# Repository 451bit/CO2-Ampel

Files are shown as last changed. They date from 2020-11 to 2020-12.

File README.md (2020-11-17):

# CO2-Ampel
ESP32 basierte CO2-Ampel für Schulen
## Inhalt
* Bau
* Programmierung
* Blynk-Server einrichten
* HTTP-Server einrichten
* Case
## Bau
* Die Pinleisten von beiden Seiten unten an den ESP anlöten. VORSICHT bei den Pins am Anschlusskabel des Displays. Der Lötkolben darf das Kabel auf keinen Fall berühren. Darauf achten, dass die Pinleisten möglichst vertikal stehen.

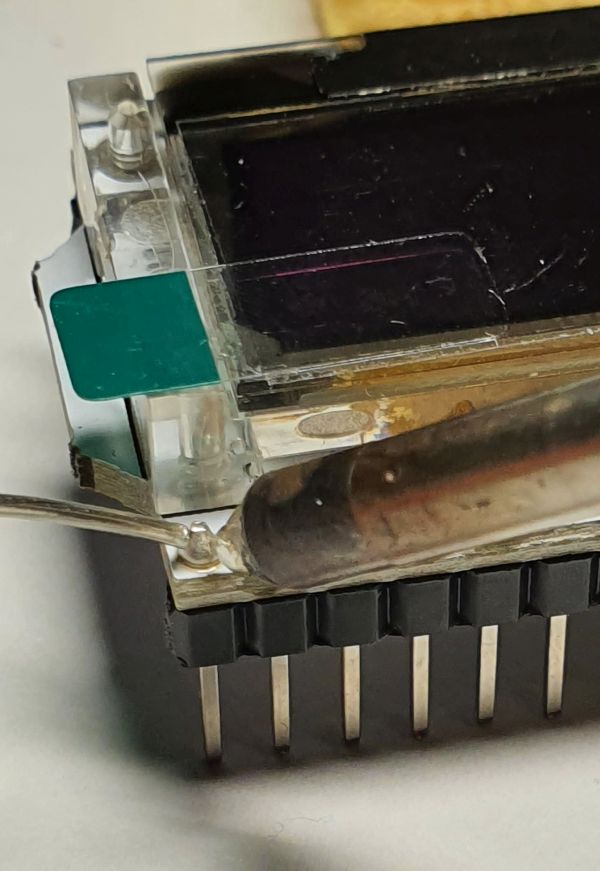
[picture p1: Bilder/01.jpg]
Bild 1

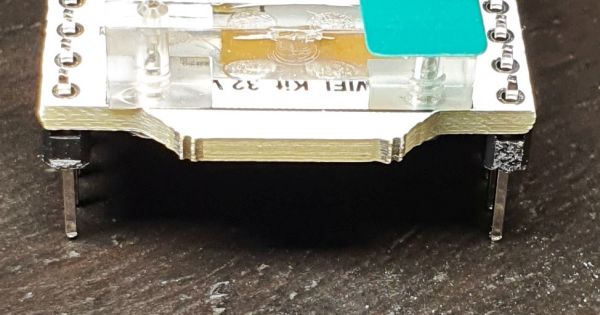
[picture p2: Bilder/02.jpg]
Bild 2


* Mit einem Multimeter an allen benachbarten Pins sicherstellen, dass keine Verbindung zwischen den Pins besteht (Widerstand sehr hoch)
* Die Pinleiste vom DHT22 mit einer Zange abknipsen und die Pin-Rest aus den Löchern entfernen (Lötzinn natürlich vorher erwärmen).

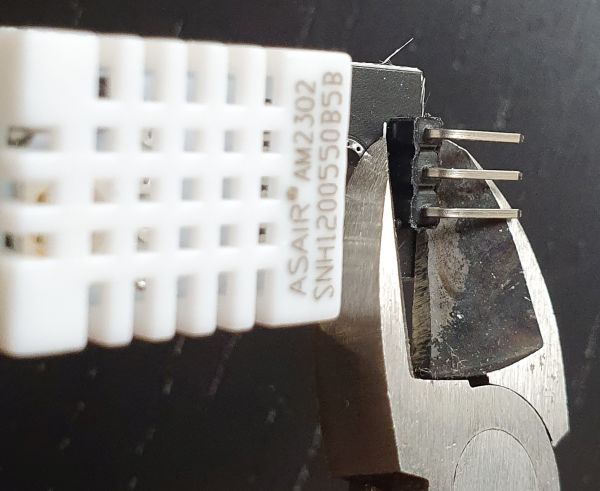
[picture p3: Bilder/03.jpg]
Bild 3

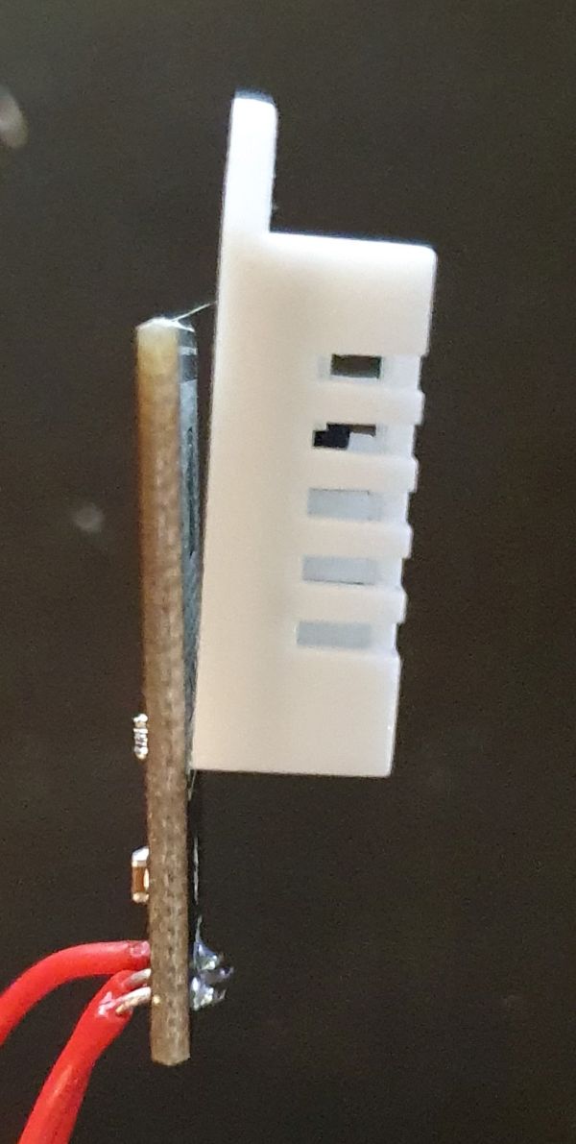
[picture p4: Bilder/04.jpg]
Bild 4


* Den Stecker-Anschluss vom Z19B mit einer Zange abknipsen.

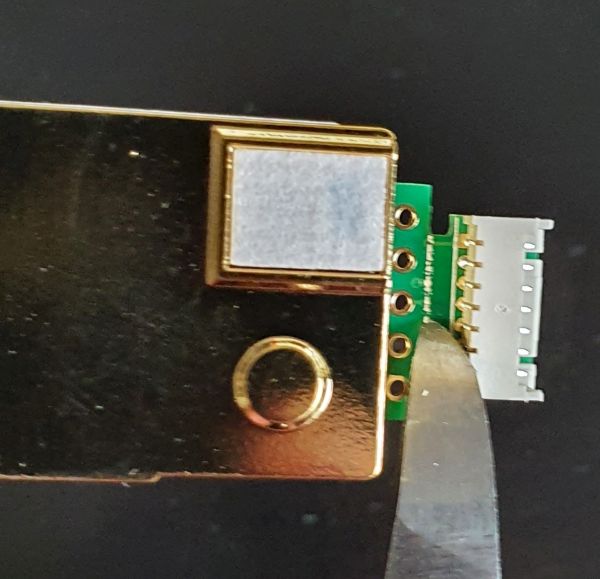
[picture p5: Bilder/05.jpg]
Bild 5

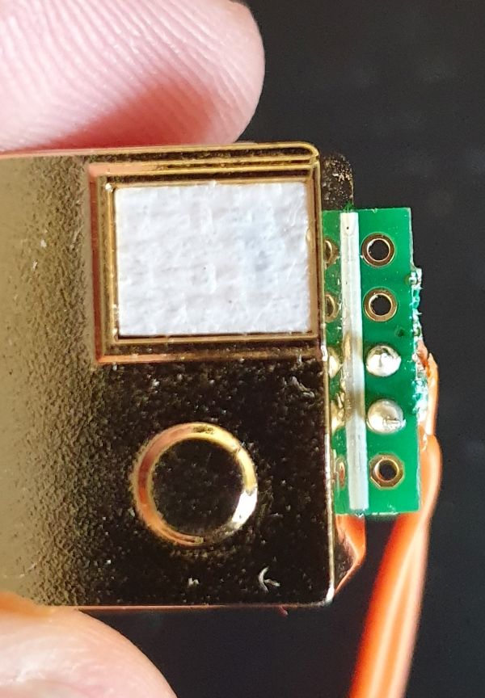
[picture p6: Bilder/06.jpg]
Bild 6


* Abstandsbolzen wie auf dem Bild an die Platine schrauben <br>

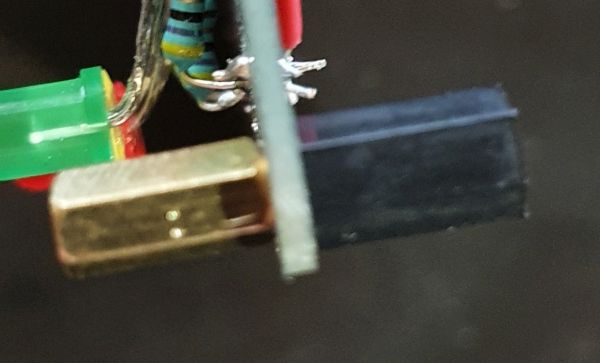
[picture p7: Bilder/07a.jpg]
Bild 7


WICHTIGE HINWEISE: Die Verkabelung exakt wie im Schaltplan einhalten (nicht wie teilweise auf den Bildern), ansonsten passt das Case evtl. nicht. 

* Den ESP, die Widerstände und die LEDs nach dem Schaltbild auf der Platine verlöten.
	* LED-Beine möglichst lang lassen, damit die LEDs variabel im Case plaziert werden können und darauf achten, dass die Kathode (kurzes Beinchen, abgeflachte Seite) wie im Schaltbild rechts ist/mit Widerstand und Gnd/- verbunden ist.
 
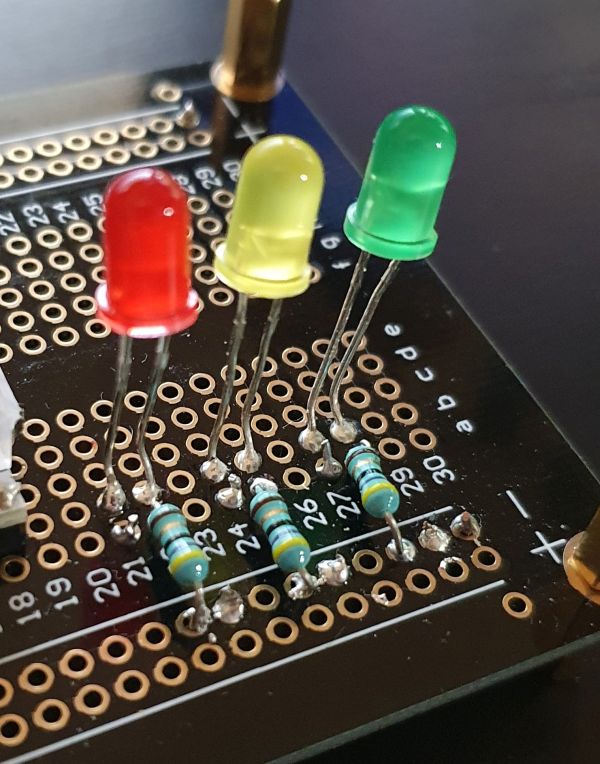
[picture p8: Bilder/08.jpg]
Bild 8

 
* Den ESP komplett in die Platine einlassen und von der Unterseite verlöten (ansonsten sitzt er zu hoch für das Case, evtl mit Tesa festkleben)
 
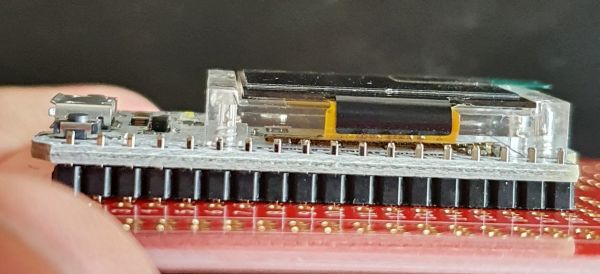
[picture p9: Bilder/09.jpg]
Bild 9

 
* Alle Kabelverbindungen auf der Unterseite der Platine verlöten (auf dem Bild sind 5V- und GND- Leiste anders als im Schaltplan verlötet, bitte an den Schaltplan halten).

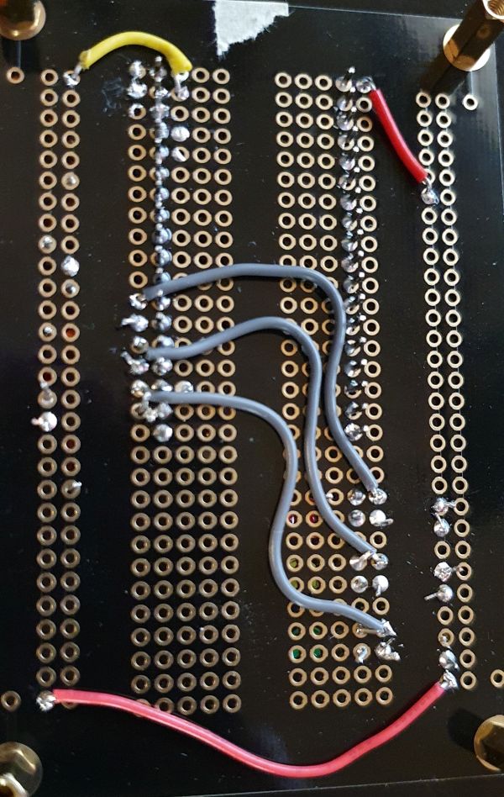
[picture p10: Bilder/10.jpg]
Bild 10


* Für den DHT22 drei und den Z19B vier relativ lange Kabel (ca. 10 cm) wählen (sie werden nicht direkt auf der Platine verlötet) und nach dem Schaltplan an die Unterseite der Sensoren und auf die Platine löten.

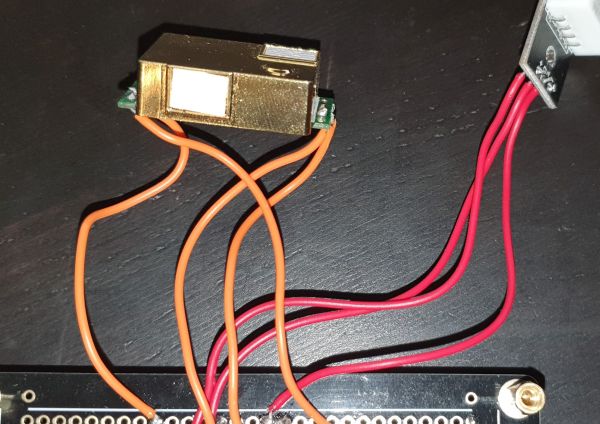
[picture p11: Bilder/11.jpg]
Bild 11


## Programmierung (bezieht sich auf Arduino-IDE auf Windows, auf MacOS sind die Einstellungen teilweise an anderen Stellen)
* Arduino-IDE herunterladen (https://www.arduino.cc/)
* Repos in der IDE einbinden:
	* Datei -> Voreinstellungen
	* Bei "Zusätzliche Boardverwalter-URLs" folgendes Einfügen: https://resource.heltec.cn/download/package_heltec_esp32_index.json
	* IDE neustarten
* Board auswählen
	* Werkzeuge -> Board -> Boardverwalter
	* Suche nach "Heltec ESP32"
	* "Heltec ESP32 Series Dev-boards" installieren und Boardverwalter schließen
	* Werkzeuge -> Board -> Heltec ESP32 Arduino -> WiFi Kit 32
* Bibliotheken einbinden
	* Werkzeuge -> Bibliotheken verwalten
	* Folgende Bibliotheken installieren:
		* Blynk
		* DHT sensor library
		* ESP32 AnalogWrite
		* Heltec ESP32 Dev-Boards
		* SimpleTimer
* Den ESP per USB-Kabel mit dem PC verbinden und unter Werkzeuge -> Port den korrekten COM-Port für den ESP wählen (meist nicht COM1) 
* Arduino-Code herunterladen und die Datei CO2-Ampel.ino in der Arduino-IDE öffnen.
* In der Configuration.h müssen die Zugangsdaten für WiFi bzw Blynk und den Webserver eingetragen werden (nur, falls die Daten online gestellt werden sollen):
* Sketch auf den ESP übertragen
## Blynk einrichten
* Blynk-App herunterladen
* Login oder Account erstellen
* Neues Projekt erstellen
	* Projektname wählen
	* Als Device ESP32 Dev Board wählen
	* Create
* Oben auf die Mutter klicken und den Auth Token per Mail senden lassen. Diesen Token in der Configuration.h bei auth[] eintragen
* Mit dem "Plus" Elemente auf der Oberfläche hinzufügen
	* z.B. Labeled Value zur Anzeige der CO2-Konzentration.
	* Als Input V0 wählen und Aktualisierungsrate auf 10 sec
	* Die weiteren Werte:
		* V0: CO2
		* V1: Temp
		* V2: Feuchtigkeit
	* Butten zum Neustart (V11) oder Kalibrieren (V10) hinzufügen
* Oben rechts "Start"-Knopf
* Wenn eigener Blynk-Server verwendet wird (https://github.com/blynkkk/blynk-server), dann in der Configuration.h anpassen. 
## HTTP-Server einrichten
* Datenbank auf einem Webspace erstellen mit Name co2ampel
	* Datenbankbenutzer co2ampel
	* Datenbankpasswort selbst wählen
	* In phpmyadmin die Datenbank wählen und mit folgendem SQL-Befehl eine Tabelle erstellen
 
    CREATE TABLE SensorData (
    id INT(6) UNSIGNED AUTO_INCREMENT PRIMARY KEY,
    sensor VARCHAR(30) NOT NULL,
    location VARCHAR(30) NOT NULL,
    valueco2 VARCHAR(10),
    valuetemp VARCHAR(10),
    valuehumid VARCHAR(10),
    reading_time TIMESTAMP DEFAULT CURRENT_TIMESTAMP ON UPDATE CURRENT_TIMESTAMP
    )

* Die readData.php und showData.php in einen öffentlichen Ordner auf dem Webserver kopieren
* Die db-config.ini in einen nicht öffentlich zugänglichen Ordner auf dem Webserver kopieren
* In der db-config.ini
	* api_key_value mit einer zufälligen Zeichenfolge belegen, die identisch in der Configuration.h unter ApiKeyValueConfig  einzutragen ist
	* DB-Passwort eintragen
* In den zwei *.php-Dateien den relativen Pfad zur db-config.ini eintragen (Zeile 2 bzw. 3)

## Case
* 3D-Modell-Vorlage herunterladen und nach eigenen Wünschen anpassen
* Board einsetzen und Sensoren wie im Bild von Oben in die Öffnungen schieben 
 * Keine Gewalt anwenden, wenn die Sensoren nicht passen müssen entweder überstehende Kabelreste von den Lötstellen entfernt oder am Case etwas gefeilt werden
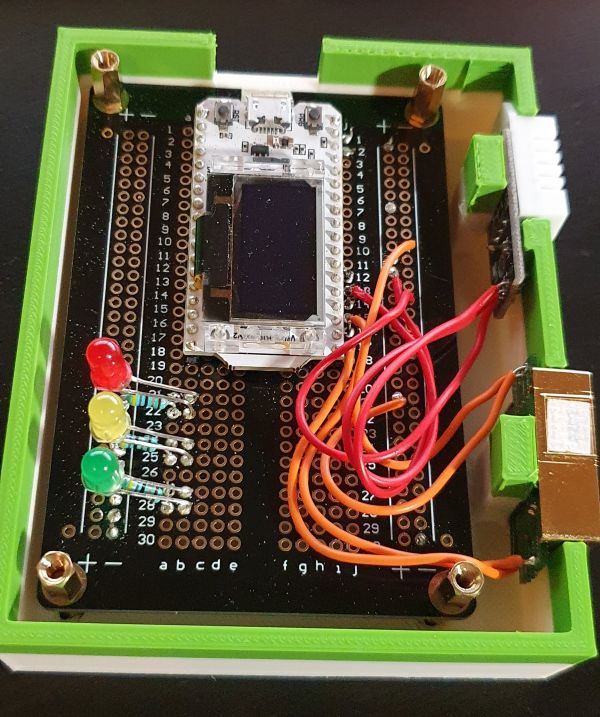
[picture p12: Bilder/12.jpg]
Bild 12

* Board von unten verschrauben
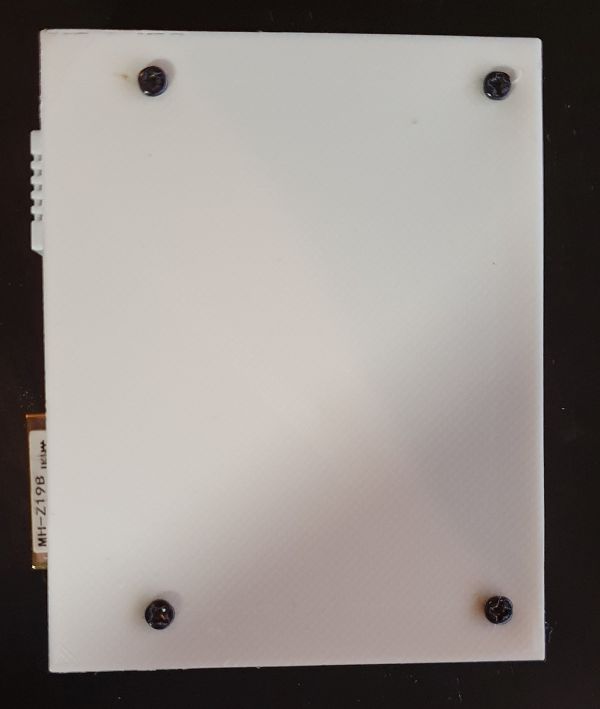
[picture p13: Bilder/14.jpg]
Bild 14

* LEDs wie im Bild oben zurechtbiegen, Deckel aufsetzen, von oben verschrauben
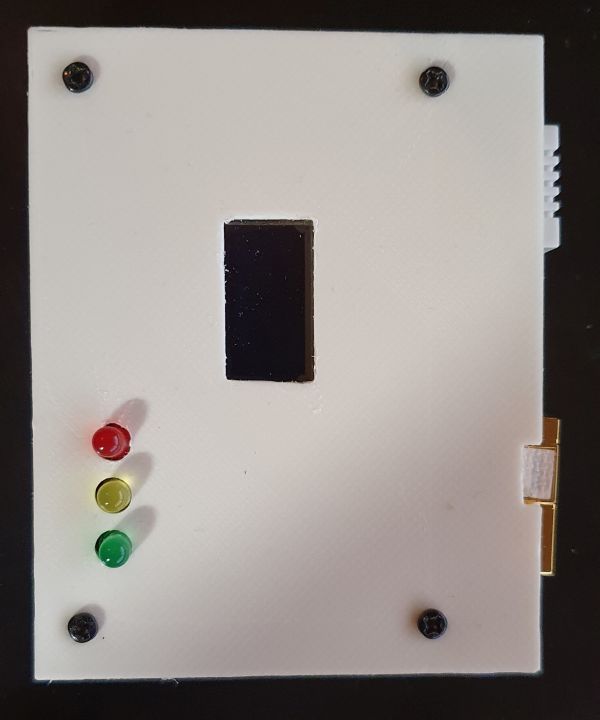
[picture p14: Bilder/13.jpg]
Bild 13

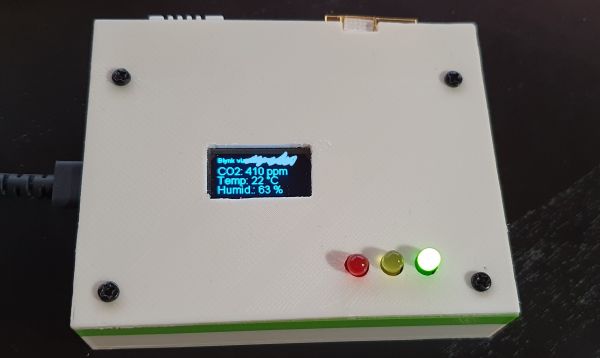
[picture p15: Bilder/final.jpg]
final


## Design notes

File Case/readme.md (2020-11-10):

Das Design des Case ist noch nicht 100% passgenau, wird noch dran gearbeitet.

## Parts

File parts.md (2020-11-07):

1. SoC: Heltec ESP32 Wifi Kit 32 (https://www.amazon.de/MakerHawk-Entwicklungs-Brett-0-96inch-Anzeige-kompatibles/dp/B076P8GRWV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)
1. CO2-Sensor: MH-Z19B (https://www.ebay.de/itm/MH-Z19B-Infrarot-CO2-Detektions-IR-Sensor-Kohlendioxyd-Monitor-Air-Quality-Modul/392943440592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)
1. Temp/Humid-Sensor: DHT22/AM2302 (https://www.amazon.de/DHT22-AM2302-Digital-Temperatur-Feuchtesensor/dp/B01DB8JH4M)
1. 3 x LED 5mm (red, yellow, green) for 3,3 V (https://www.ebay.de/itm/10-x-3mm-5mm-Diffused-LED-White-Red-Green-Blue-Orange-Yellow-Bi-RGB-Arduino-UK/153013273135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)
1. 3 x 47 Ohm resistor (https://www.amazon.de/Widerstand-Verwendbar-Resistor-Suitable-A2401/dp/B07KX4LZB6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)
1. Proto Board (https://www.amazon.de/gp/product/B081YK5Z2Z/ref=ppx_yo_dt_b_asin_title_o07_s00?ie=UTF8&psc=1)
1. Zusätzliche Abstandsbolzen (https://www.amazon.de/gp/product/B07CG36VYC/ref=ox_sc_act_title_1?smid=A2F7JN9V2AWTSH&psc=1)
1. Diverse Kabel (https://www.amazon.de/gp/product/B07PRGFW5Z/ref=ppx_yo_dt_b_asin_title_o07_s00?ie=UTF8&psc=1)

1. Micro-USB-Kabel + USB-Netzteil
1. Lötkolben (fein, für Elektronik)
1. Lötzinn
1. Dritte Hand
1. Multimeter
1. Kleine Zange
1. Heißklebepistole

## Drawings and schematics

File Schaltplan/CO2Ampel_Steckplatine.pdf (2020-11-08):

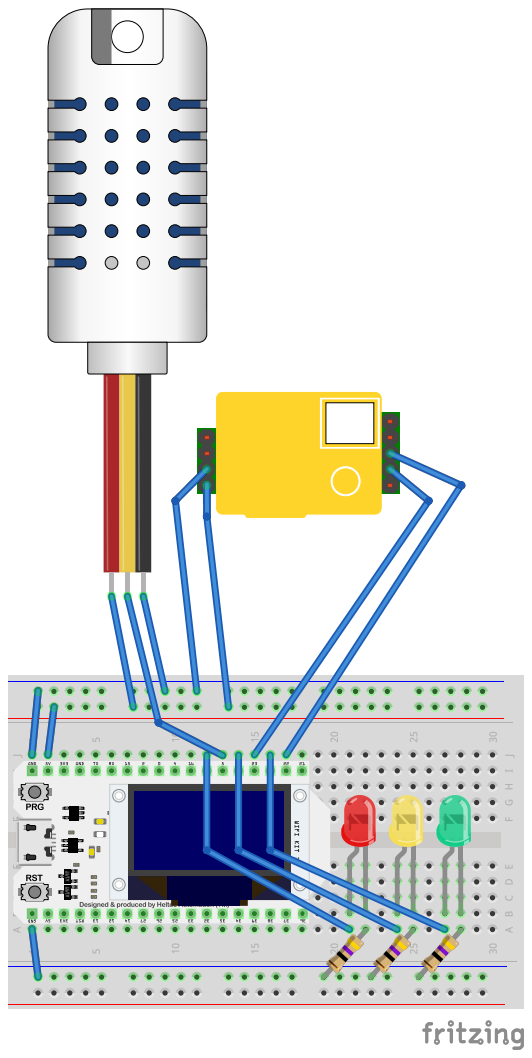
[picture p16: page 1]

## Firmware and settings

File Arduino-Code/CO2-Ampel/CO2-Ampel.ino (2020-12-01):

#include <Arduino.h>
#include "Configuration.h"
#include "heltec.h"
#include <WiFiMulti.h>
#include <BlynkSimpleEsp32_SSL.h>
#include <ArduinoOTA.h>
#include <analogWrite.h>
#include "DHT.h"
// Temp-Sensor Typ
#define DHTTYPE DHT22
#include <HTTPClient.h>
#include <InfluxDbClient.h>
#include <InfluxDbCloud.h>

// Blynk Variablen
char BlynkServer[] = BlynkServerConfig;
uint16_t BlynkServerPort = BlynkServerPortConfig;
char auth[] = BlynkAuthConfig;

// Server Variablen
String sensorName = SensorNameConfig;
String sensorLocation = SensorLocationConfig;
String apiKeyValue = ApiKeyValueConfig;
const char* serverName = ServerNameConfig;


// Influx Variablen
InfluxDBClient client(INFLUXDB_URL, INFLUXDB_ORG, INFLUXDB_BUCKET, INFLUXDB_TOKEN, InfluxDbCloud2CACert);
Point sensor("data_point");

// Wifi Variablen
String SSID_1 = SSID1Config;
String WIFI_PW_1 = WiFiPwConfig1;
String SSID_2 = SSID2Config;
String WIFI_PW_2 = WiFiPwConfig2;
String SSID_3 = SSID3Config;
String WIFI_PW_3 = WiFiPwConfig3;
WiFiMulti wifiMulti;
String MYSSID = "";
char ssid_char[50];
char pw_char[50];
String OTAString = "CO2-Ampel-" + String(SensorNameConfig);
const char* OTAName = OTAString.c_str();

//Pin-Belegung
int Ser2TX = 23;  // Serial 2 TX Pin to CO2-Sensor RX
int Ser2RX = 22;  // Serial 2 RX Pin to CO2-Sensor TX
int grnPin = 19;  // Pins der LEDs
int yelPin = 18;
int redPin = 17;
#define DHTPIN 5
DHT dht(DHTPIN, DHTTYPE);

//Sensorwerte
int CO2ppm = 0;
int Temp = 0;
int Humid = 0;
boolean CO2Status = false, TempStatus = false, HumidStatus = false;

// Kommandos zum Lesen und Kalibrieren des Sensors
byte cmd[9] = {0xFF, 0x01, 0x86, 0x00, 0x00, 0x00, 0x00, 0x00, 0x79};  // Lesebefehl
byte cmdCal[9] = {0xFF, 0x01, 0x87, 0x00, 0x00, 0x00, 0x00, 0x00, 0x78};  // Kalibrier-Befehl
char response[9];  // Antwort des Sensors

// Timer
int TimerWarmup = 10; // Warumup-Timer
SimpleTimer TimerRefresh; // Timer zum Aktualisieren der Daten
int TimerRefreshInterval = 10;
SimpleTimer TimerWifi; // Timer zur Prüfung der Netzwerkverbindung
int TimerWifiInterval = 1;
SimpleTimer TimerUpload; // Timer zum Upload der Daten
int TimerUploadInterval = 30;

// Initialisierung und Timer zum Aktualisieren der Sensordaten Starten
void setup() {
  initSerial(Ser2RX, Ser2TX);
  initOLED();
  initLED();
  initDHT();
  initWifi();
  initBlynk();
  initFlux();
  warumup();
  TimerRefresh.setInterval(TimerRefreshInterval * 1000, refresh);
  TimerWifi.setInterval(TimerWifiInterval * 1000, ConnectWifi);
  TimerUpload.setInterval(TimerUploadInterval * 1000, upload);
}

// OTA und Timer abfragen
void loop() {
  ArduinoOTA.handle();
  TimerRefresh.run();
  TimerWifi.run();
  TimerUpload.run();
  BlynkRun();
  delay(100);
}

// Refresh-Timer-Methode
void refresh() {
  readSensor();
  readDHT();
  displayData();
  LEDStatus();
  writeDataSerial();
}

// Upload-Timer-Methode
void upload() {
  uploadBlynk();
  char empty[] = "";
  if (memcmp(serverName, empty, 1)) {
    // Eigener Server
    uploadServer();
    // Influx-Upload
    uploadFlux();
  }
}

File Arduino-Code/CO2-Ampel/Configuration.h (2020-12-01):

// Daten für Blynk
#define BlynkServerConfig ""  // Hier eingenen Blynk-Server eintragen oder leer "" lassen
#define BlynkServerPortConfig 9443  // Port für Blynk-Server
//#define BLYNK_SSL_USE_LETSENCRYPT // diese Zeile nur aktivieren, wenn für den eigenen Blynk-Server ein Letsencrypt-Certifikat verwendet wird
#define  BlynkAuthConfig "******" // Blynk-Auth-Code aus der App

// Daten für HTTP-Server
#define  SensorLocationConfig "OrtDesSensors" // Bezeichnung des Gebäudes oder Raums für den Sensor
#define  SensorNameConfig "SensorName"  // Eindeutiger Name für den Sensor
#define  ApiKeyValueConfig "******" // ApiKey für den Upload auf den Server (identisch mit ApiKey in readData.php)
#define  ServerNameConfig "https://pfad.zur/readData.php" // URL zur readData.php

// WIFIs
#define  SSID1Config "SsidWlan1"  // SSID für Wifi 1 (z.B. in der Schule)
#define  WiFiPwConfig1 "******"             // Passwort für Wifi 1
#define  SSID2Config ""     // SSID für Wifi 2 (z.B. zuhause)
#define  WiFiPwConfig2 "" // Passwort für Wifi 2
#define  SSID3Config ""               // SSID für Wifi 3
#define  WiFiPwConfig3 ""             // // Passwort für Wifi 3

// Influx
#define INFLUXDB_URL "https://pfad.zur.influxdb.com:8086" // Influx URL und Port
#define INFLUXDB_TOKEN "***********" // Influx Token, aus Influx auslesen
#define INFLUXDB_ORG "co2amepl" // Influx Org Name
#define INFLUXDB_BUCKET "co2ampel" // Influx Bucket
#define TZ_INFO "CET-1CEST,M3.5.0,M10.5.0/3" // Standardzeitzone, hier Mitteleuropa

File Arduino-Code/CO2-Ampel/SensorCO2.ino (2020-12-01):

// Sensor auslesen: Dokumentation zum Read-Cmd und zur Berechnung auf der Herstellerwebsite
void readSensor() {
  // Serial-Buffer leeren
  while (Serial2.available())
  {
    int garbage = Serial2.read();
  }

  // Read-Cmd an Sensor senden
  Serial2.write(cmd, 9);

  // Pausiert und wartet bis TX buffer gesendet hat
  Serial2.flush();

  // Sensordaten empfangen
  int StartTime = millis();
  int Timer = 0;

  // Pausiert und wartet 5 Sekunden auf Antwort des Sensors
  while (!Serial2.available() && Timer < 5000)
  {
    Timer = millis() - StartTime;
    delay(100);
  }

  //Schreibt Sensordaten in Var response
  Serial2.readBytes(response, 9);

  // Berechnet CO2 und schreibt Wert in Variable CO2ppm
  int responseHigh = (int)response[2];
  int responseLow = (int)response[3];
  int CO2raw = (256 * responseHigh) + responseLow;
  if (CO2raw > 200 && CO2raw < 4999) {
    CO2ppm = CO2raw;
    CO2Status = true;    
  } else {
    CO2ppm = 0;
    CO2Status = false;
  }
}
